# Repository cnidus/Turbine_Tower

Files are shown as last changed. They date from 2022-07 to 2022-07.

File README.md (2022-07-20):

# Turbine_Tower
This project is to document the hardware & software lighting solution for my friend's vertical wind turbine (WindSpire).

## Hardware overview
I used [Joel's Antenna2022](https://github.com/jspolsky/Antenna2022) project as a starting point for the hardware. Joel had the idea of transmitting [data and power via Cat6 cable](https://www.blinkylights.blog/2022/05/23/single-cat-6-power-and-data-for-ws2815-led-strips/), utilizing  RS-422 differential signalling for the data lines and use 6 conductors for power, which I thought was a really clean solution.

### Lighting Controller (cat6 output expander)
For my variant, I wanted to use [PixelBlaze v3](https://shop.electromage.com/products/pixelblaze-v3-standard-wifi-led-controller) as the controller. The PB is responsible for creating the patterns etc and I'm also utilizing one of Ben's output expander boards to get 6 individual lighting channels.

The controller serves three purposes:
1. Distribute 12V power to the LED strips over Cat6 ethernet cable,
2. Take the TTL data signal from the PixelBlaze output expander and convert into RS-422 via a MAX485
3. Mount the PB controller and output expander boards directly to my board, which required a 5V linear converter and power bus.

Here's the PCB:
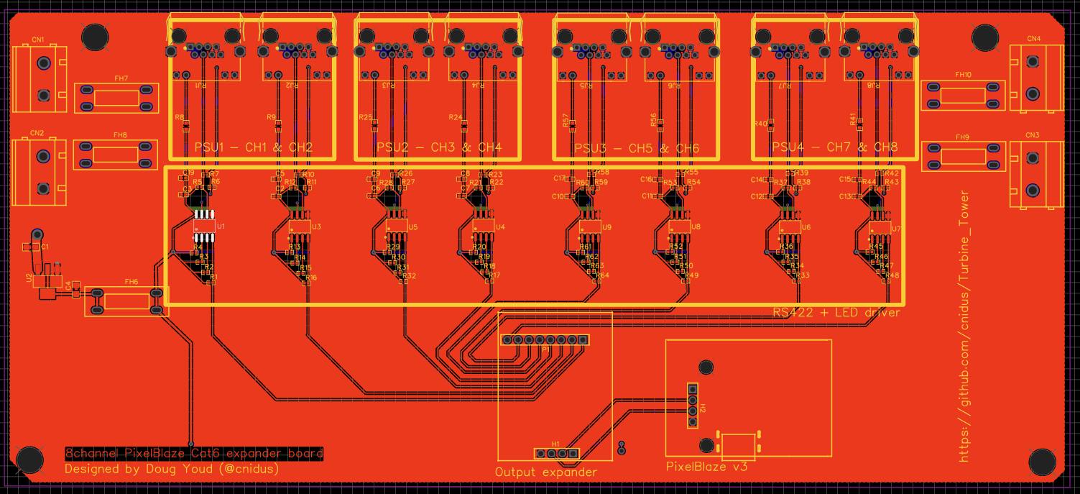
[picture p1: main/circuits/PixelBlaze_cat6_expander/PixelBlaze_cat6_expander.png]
Output Expander PCB


Here's the circuit diagram:
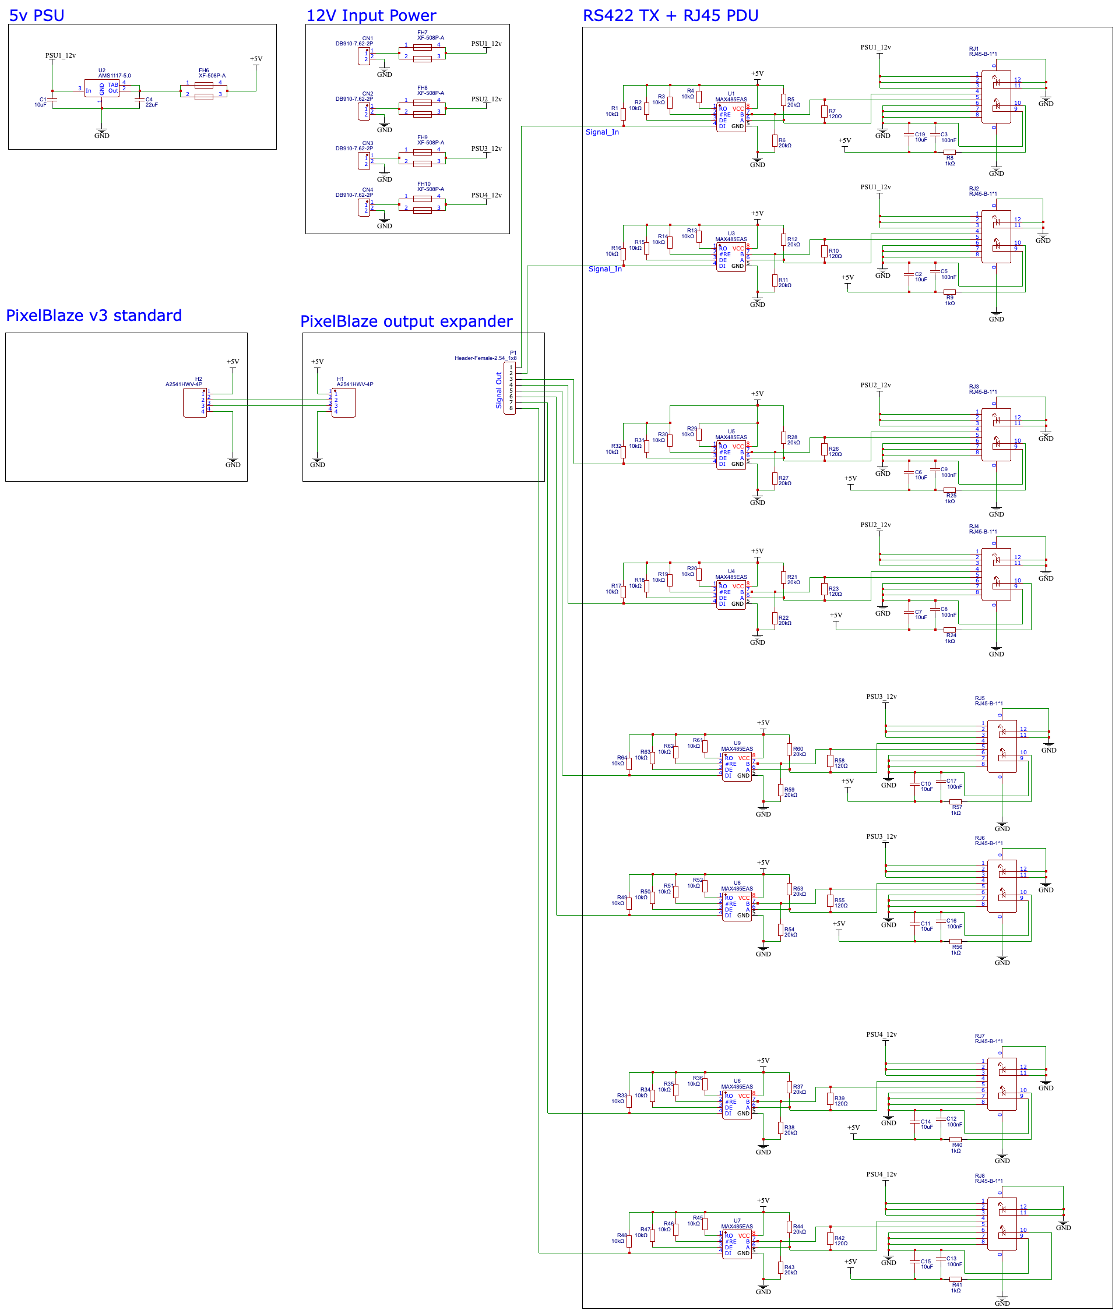
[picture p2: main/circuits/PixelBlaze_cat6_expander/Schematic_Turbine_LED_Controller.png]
Output Expander PCB


### Receiver boards
These are the same as Joel's implementation, they mount close to each strip.

Input = Cat6 with 12v power and RS422 signal sent from the controller.
Output = 12V power for WS2815 strips and TTL data out

I literally just grabbed Joel's gerbers and ordered a bunch from JLCPCB. Thanks to Joel for making these public and for helping me walk through my first JLCPCB order.

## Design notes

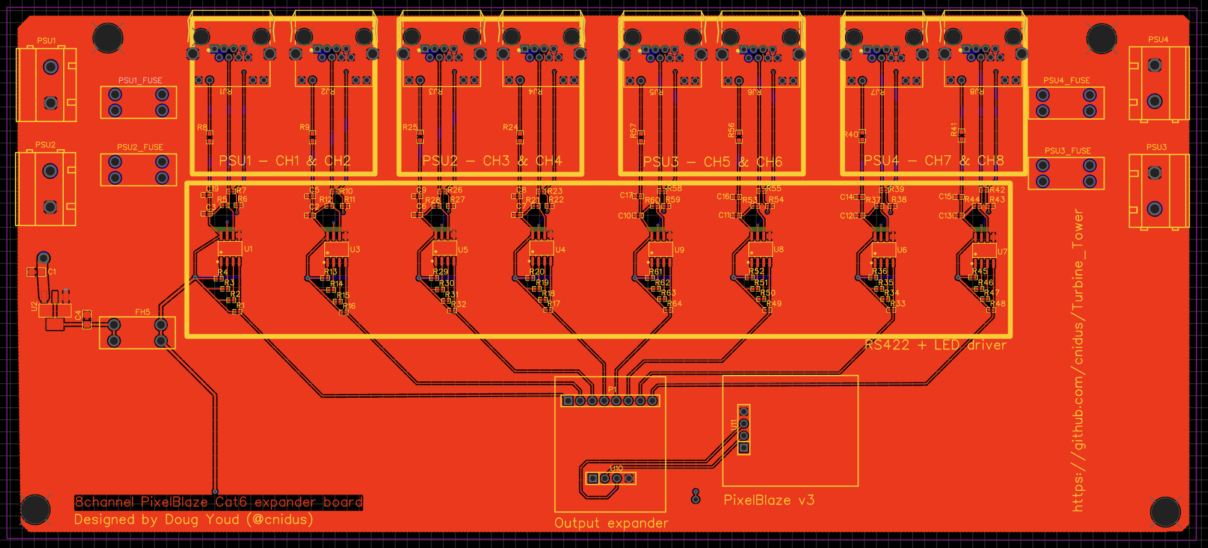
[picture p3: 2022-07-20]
main/circuits/PixelBlaze_cat6_expander/PixelBlaze_cat6_expander_v1.png

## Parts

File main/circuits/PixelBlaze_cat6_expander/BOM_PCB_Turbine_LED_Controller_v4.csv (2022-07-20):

ID | Name | Designator | Footprint | Quantity | Manufacturer Part | Manufacturer | Supplier | Supplier Part | Price | Pins | 3DModel | JLCPCB Part Class | Contributor | Resistance (Ohms) | link
1 | XF-508P-A | 5V_FUSE,PSU1_FUSE,PSU2_FUSE,PSU3_FUSE,PSU4_FUSE | FUSE-TH_L19.8-W7.0_XF-508P-A | 5 | XF-508P-A | XFCN(台湾兴飞) | LCSC | C2935469 | 0.293 | 4 | FUSE-TH_L19.8-W7.0_XF-508P-A | Extended Part | LCSC |  | https://atta.szlcsc.com/upload/public/pdf/source/20211224/AEF22AC18F7D7A25339F9E12C8281FBC.pdf
2 | A2541HWV-4P | H1,H2 | HDR-TH_4P-P2.54-V_A2541HWV-4P | 2 | A2541HWV-4P | Changjiang Connectors | LCSC | C225501 | 0.083 | 4 | HDR-F-2.54_1x4 | Extended Part | LCSC |  | https://item.szlcsc.com/225784.html
3 | DB910-7.62-2P | PSU1,PSU2,PSU3,PSU4 | CONN-TH_2P-P7.62_DB910-7.62-2P | 4 | DB910-7.62-2P | DIBO | LCSC | C395876 | 0.236 | 2 | CONN-TH_2P-P7.62_DB910-7.62-2P | Extended Part | LCSC |  | https://item.szlcsc.com/376623.html
4 | 10uF | C19,C2,C6,C7,C10,C11,C14,C15 | C0402 | 8 | JMK105CBJ106MV-F | TAIYO YUDEN | LCSC | C87148 | 0.012 | 2 | C0402_L1.0-W0.5-H0.5 | Extended Part | lcsc |  | https://item.szlcsc.com/15869.html
5 | RJ45-B-1*1 | RJ1,RJ2,RJ3,RJ4,RJ5,RJ6,RJ7,RJ8 | RJ45-TH_B-1-1 | 8 | RJ45-B-1*1 | BOOMELE | LCSC | C138392 | 0.271 | 14 | RJ45-TH_B-1-1 | Extended Part | LCSC |  | https://item.szlcsc.com/149710.html
6 | 10uF | C1 | C0805 | 1 | CL21A106KAYNNNE | SAMSUNG | LCSC | C15850 | 0.007 | 2 | C0805_L2.0-W1.3-H1.3 | Basic Part | lcsc |  | https://item.szlcsc.com/373011.html
7 | 22uF | C4 | C0805 | 1 | 0805X226M250NT | FH | LCSC | C129303 | 0.051 | 2 | C0805_L2.0-W1.3-H1.3 | Extended Part | lcsc |  | https://item.szlcsc.com/373011.html
8 | 100nF | C3,C5,C8,C9,C12,C13,C16,C17 | C0402_NEW | 8 | CL05B104KO5NNNC | SAMSUNG | LCSC | C1525 | 0.001 | 2 | C0402_L1.0-W0.5-H0.5 | Basic Part | 立创EDA官方封装库 |  | https://item.szlcsc.com/15869.html
9 | Header-Female-2.54_1x8 | P1 | HDR-TH_8P-P2.54-V-F-1 | 1 | Female headerHDR1X8-2.54 | BOOMELE | LCSC | C27438 | 0.072 | 8 | HDR-F-2.54_1x8 | Extended Part | 官方封装库 |  | https://item.szlcsc.com/290266.html
10 | 10kΩ | R1,R2,R3,R4,R13,R14,R15,R16,R17,R18,R19,R20,R29,R30,R31,R32,R33,R34,R35,R36,R45,R46,R47,R48,R49,R50,R51,R52,R61,R62,R63,R64 | R0402 | 32 | ERJ-2RKF1002X | PANASONIC | LCSC | C191123 | 0.006 | 2 | R0402_L1.0-W0.5-H0.5 | Extended Part | LCSC | 10K | https://item.szlcsc.com/323315.html
11 | 20kΩ | R5,R6,R11,R12,R21,R22,R27,R28,R37,R38,R43,R44,R53,R54,R59,R60 | R0402 | 16 | WR04X2002FTL | WALSIN | LCSC | C163819 | 0.001 | 2 | R0402_L1.0-W0.5-H0.5 | Extended Part | LCSC | 20K | https://item.szlcsc.com/323315.html
12 | 120Ω | R7,R10,R23,R26,R39,R42,R55,R58 | R0402 | 8 | ERJ2GEJ121X | PANASONIC | LCSC | C412974 | 0.005 | 2 | R0402_L1.0-W0.5-H0.5 | Extended Part | LCSC | 120 | https://item.szlcsc.com/323315.html
13 | 1kΩ | R8,R9,R24,R25,R40,R41,R56,R57 | R0603 | 8 | 0603WAF1001T5E | UniOhm | LCSC | C21190 |  | 2 | R0603_L1.6-W0.8-H0.8 | Basic Part | lcsc | 1K | https://www.mouser.in/datasheet/2/447/PYu_RT_1_to_0_01_RoHS_L_11-1669912.pdf
14 | MAX485EAS | U1,U3,U4,U5,U6,U7,U8,U9 | SOP-8_L5.0-W4.0-P1.27-LS6.0-BL | 8 | MAX485EAS | UMW(Youtai Semiconductor Co., Ltd.) | LCSC | C668206 | 0.426 | 8 | SOP-8_L5.0-W4.0-H1.8-LS6.2-P1.27 | Extended Part | LCSC |  | https://item.szlcsc.com/7378.html
15 | AMS1117-5.0 | U2 | SOT-223_L6.5-W3.5-P2.30-LS7.0-BR | 1 | AMS1117-5.0 | AMS | LCSC | C6187 | 0.152 | 4 | SOT-223-4P_L6.5-W3.5-H1.6-LS7.0-P2.30 | Basic Part | lcsc |  | https://item.szlcsc.com/109711.html

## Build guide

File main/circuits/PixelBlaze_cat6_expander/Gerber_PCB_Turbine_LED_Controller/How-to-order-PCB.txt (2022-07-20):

How to Order PCB

Please refer to:
https://docs.easyeda.com/en/PCB/Order-PCB

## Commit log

2022-07-20 Pushing cat6_expander v1 and v2. V2 replaces a coupel of parts JLCPCB doesnt have in stock.
    [BOM_PCB_Turbine_LED_Controller_2022-07-19.csv, BOM_PCB_Turbine_LED_Controller_v2.csv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]
2022-07-20 add schematic.
2022-07-20 update v3 design with proper pixelBlaze pin placement (Thanks Ben for the DXf's!)
    [BOM_PCB_Turbine_LED_Controller_v3.csv, PickAndPlace_PCB_Turbine_LED_Controller_v3.csv]
2022-07-20 Adding v4 of the board, fixed board outline and beefed up 5v rail.
    [BOM_PCB_Turbine_LED_Controller_v4.csv, PickAndPlace_PCB_Turbine_LED_Controller_v4.csv]
